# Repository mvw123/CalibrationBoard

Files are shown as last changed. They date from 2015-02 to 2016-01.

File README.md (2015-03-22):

CalibrationBoard
================

Reference board for calibration of Voltage, current, resistance Capacitance and Inductance
The design is created in Eagle CAD v 6.5.0 (free version) and uses the standard PCB board size.

CAD B - [WIP]
====================================
Work in progress

CAD A - [WIP]
====================================

The board has been manufactured at PCB fabricator ITead
Some issues have been noted with the PCB. See issues list in github. 

Basic tests indicate the board works, but needs a CAD B to correct some PCB issues. 

Specification: 
==============
Voltage reference -> 2.5V and 5.0V < 10mA load
Current Reference -> Configurable up to 10A max
Resistance references -> Various tight tolerance resistors <=1 ohm = 1%, >1 ohm = 0.1%
Capacitors -> TBD
Inductors -> TBD

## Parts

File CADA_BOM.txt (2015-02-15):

Order list for /Users/guvvy/Documents/github/eagle/CalibrationBoard/CalibrationBoard.sch
Exported from EAGLE with DesignLink

Quantity	Value	Package	Order code	Manufacturer	Manuf. Code	Availability	Price (from)	Description
1	+9V_BATTERY_HOLDER	BC9VPC	unknown					
7	2.2uF	C0805	unknown					
3	0.1uF	C0805	unknown					
2	1uF	C0805	unknown					
1	47pF	C0805	2332727	AVX	08052U470FAT2A	3770	0.088	AVX - 08052U470FAT2A - CAP, MLCC, C0G/NP0, 47PF, 200V, 0805
1	1.2nF	C0805	1650948	VISHAY VITRAMON	VJ0805A122FXBMT	5863	0.0403	VISHAY VITRAMON - VJ0805A122FXBMT - CAP, MLCC, C0G/NP0, 1.2NF, 100V, 0805
1	10nF	C0805	unknown					
1	100nF	C0805	1740673	AVX	08055C104JAT2A	203426	0.0155	AVX - 08055C104JAT2A - CAP, MLCC, X7R, 100NF, 50V, 0805
1	10uF	C0805	unknown					
1	100uF	E5-10,5	unknown					
1	MBR60H100CTG	TO220ABS	1431072	ON SEMICONDUCTOR	MBR60H100CTG	665	0.501	ON SEMICONDUCTOR - MBR60H100CTG - DIODE, SCHOTTKY, 60A, 100V, TO-220
1	12A	LITTLEFUSE	1345957	TE CONNECTIVITY / RAYCHEM	RGEF1200	110	0.351	TE CONNECTIVITY / RAYCHEM - RGEF1200 - POLYSWITCH, RADIAL, 12A
1	1.1A	1812	1345925	TE CONNECTIVITY / RAYCHEM	MINISMDC110F/24-2	2983	0.188	TE CONNECTIVITY / RAYCHEM - MINISMDC110F/24-2 - POLYSWITCH, SMD, 1812, 1.1A
5	BANANA_CONN_RED	BANANA_CONN	1011402	HIRSCHMANN TEST AND MEASUREMENT	972354101	1602	2.04	HIRSCHMANN TEST AND MEASUREMENT - 972354101 - BANANA SOCKET, 32A, 4MM, PANEL, RED
4	BANANA_CONN_BLACK	BANANA_CONN	1011402	HIRSCHMANN TEST AND MEASUREMENT	972354101	1602	2.04	HIRSCHMANN TEST AND MEASUREMENT - 972354101 - BANANA SOCKET, 32A, 4MM, PANEL, RED
1	SK104-PAD	SK104-PAD	1319811	FISCHER ELEKTRONIK	SK 129 38,1 STS	231	1.14	FISCHER ELEKTRONIK - SK 129 38,1 STS - HEAT SINK, EXTRUDED, PCB MOUNTING
1	1nH	L1812	unknown					
1	330nH	L2825P	2333647	BOURNS	CW252016-R33G	1849	0.136	BOURNS - CW252016-R33G - INDUCTOR, 330NH, 2%, 0.5A, SMD
1	1uH	L1812	2287053	COILCRAFT	1812PS-102JLC	778	0.724	COILCRAFT - 1812PS-102JLC - INDUCTOR, PWR, 1UH, 2.7A, 5%, 685MHZ
1	100uH	L1812	2287073	COILCRAFT	1812PS-104JLB	75	0.63	COILCRAFT - 1812PS-104JLB - INDUCTOR, PWR, 100UH, 0.65A,5%,14MHZ
1	4.7mH	6000-XXXX-RC	2211696	WURTH ELEKTRONIK	7447721047	150	0.514	WURTH ELEKTRONIK - 7447721047 - INDUCTOR, POWER, 4700UH, 5%, 9.5X9.5MM
1	RED_LED	P-LCC-2	1519491	DIALIGHT	597-3121-207F	1506	0.148	DIALIGHT - 597-3121-207F - LED, PLCC, RED
1	OSHW-LOGOL	OSHW-LOGO-L	unknown					
6	MOUNT_HOLE	3,81/1,4	unknown					
1	IRF3708PBF	TO220BV	8648158	INTERNATIONAL RECTIFIER	IRF3708PBF	30657	0.406	INTERNATIONAL RECTIFIER - IRF3708PBF - MOSFET, N, 30V, 62A, TO-220
1	2k	R0805	unknown					
1	25R	R0805	unknown					
1	0.1R	R0805	1717785	PANASONIC ELECTRONIC COMPONENTS	ERJ6RSFR10V	2973	0.051	PANASONIC ELECTRONIC COMPONENTS - ERJ6RSFR10V - RESISTOR, 0805, 0.125W, 1%, 0R1
1	1R	R0805	2333617	BOURNS	CR0805-FX-1R00ELF	10228	0.0107	BOURNS - CR0805-FX-1R00ELF - RESISTOR THICK FILM, 1OHM, 1%, 0805
1	5R	R0805	unknown					
1	10R	R0805	2008313	BOURNS	CRT0805-BY-10R0ELF	8362	0.0876	BOURNS - CRT0805-BY-10R0ELF - RESISTOR, 0805, 10R, 0.1%, 1/8W
1	50R	R0805	unknown					
1	100R	R0805	1653279	SUSUMU	RR1220P-101-B-T5	2178	0.0536	SUSUMU - RR1220P-101-B-T5 - THIN FILM CHIP RESISTOR
1	1k	R0805	1577659	PANASONIC ELECTRONIC COMPONENTS	ERA6AEB102V	19999	0.0515	PANASONIC ELECTRONIC COMPONENTS - ERA6AEB102V - RESISTOR, THIN FILM, 1K, 0.125W, 0.1%
1	5k	R0805	unknown					
1	10k	R0805	1653282	SUSUMU	RR1220P-103-B-T5	25199	0.0536	SUSUMU - RR1220P-103-B-T5 - RESISTOR, THIN FILM, 10K, 0.1W, 0.1%
1	100k	R0805	1653285	SUSUMU	RR1220P-104-B-T5	13652	0.0524	SUSUMU - RR1220P-104-B-T5 - THIN FILM CHIP RESISTOR
1	1Meg	R0805	1653287	SUSUMU	RR1220P-105-B-T5	4133	0.0536	SUSUMU - RR1220P-105-B-T5 - THIN FILM CHIP RESISTOR
1	10Meg	R0805	unknown					
1	5649A	320-938	1082316	APEM	5649A	52	1.39	APEM - 5649A - SWITCH, DPDT, CTR OFF
49	TP_1MM_TH"	TP_1MM_TH	unknown					
2	MAX6126AASA25+	SOIC127P600X175-8N	1673170	MAXIM INTEGRATED PRODUCTS	MAX6126AASA25+	83	5.13	MAXIM INTEGRATED PRODUCTS - MAX6126AASA25+ - IC, V REF, ULTRA-HI, 2.5V, 8-SOIC
1	MAX6126AASA50+	SOIC127P600X175-8N	unknown

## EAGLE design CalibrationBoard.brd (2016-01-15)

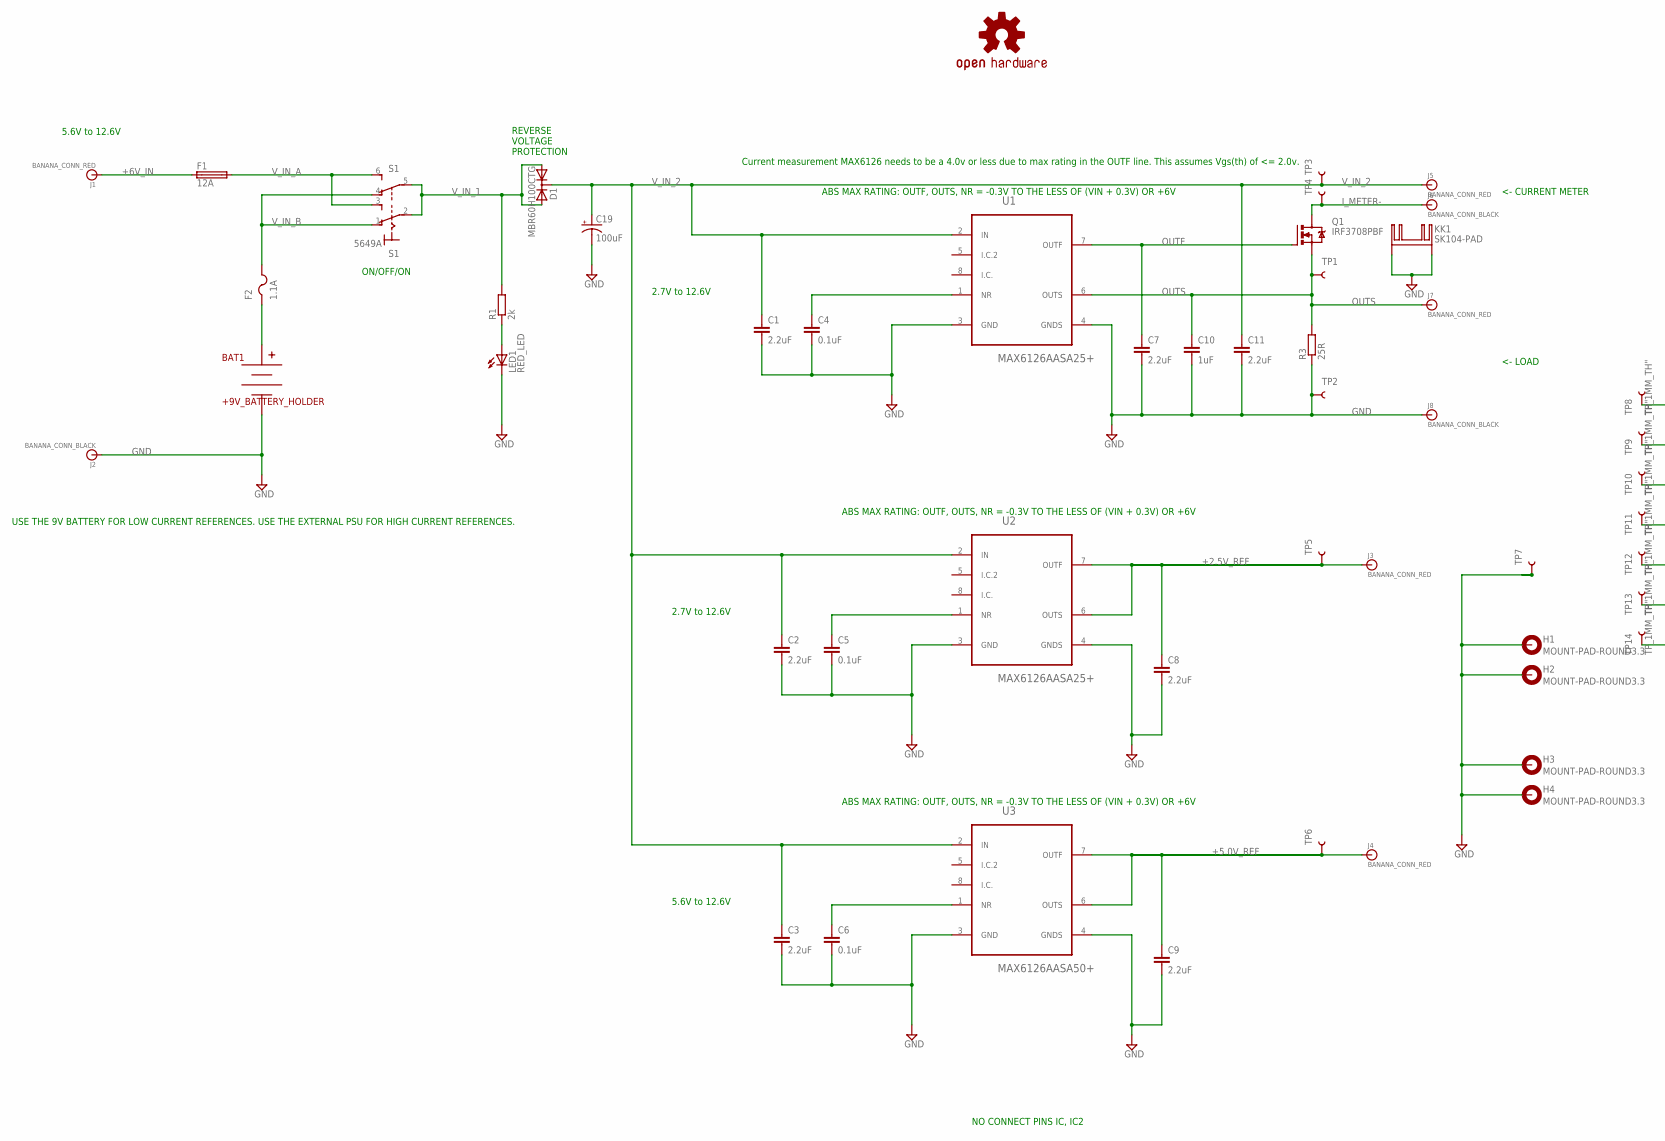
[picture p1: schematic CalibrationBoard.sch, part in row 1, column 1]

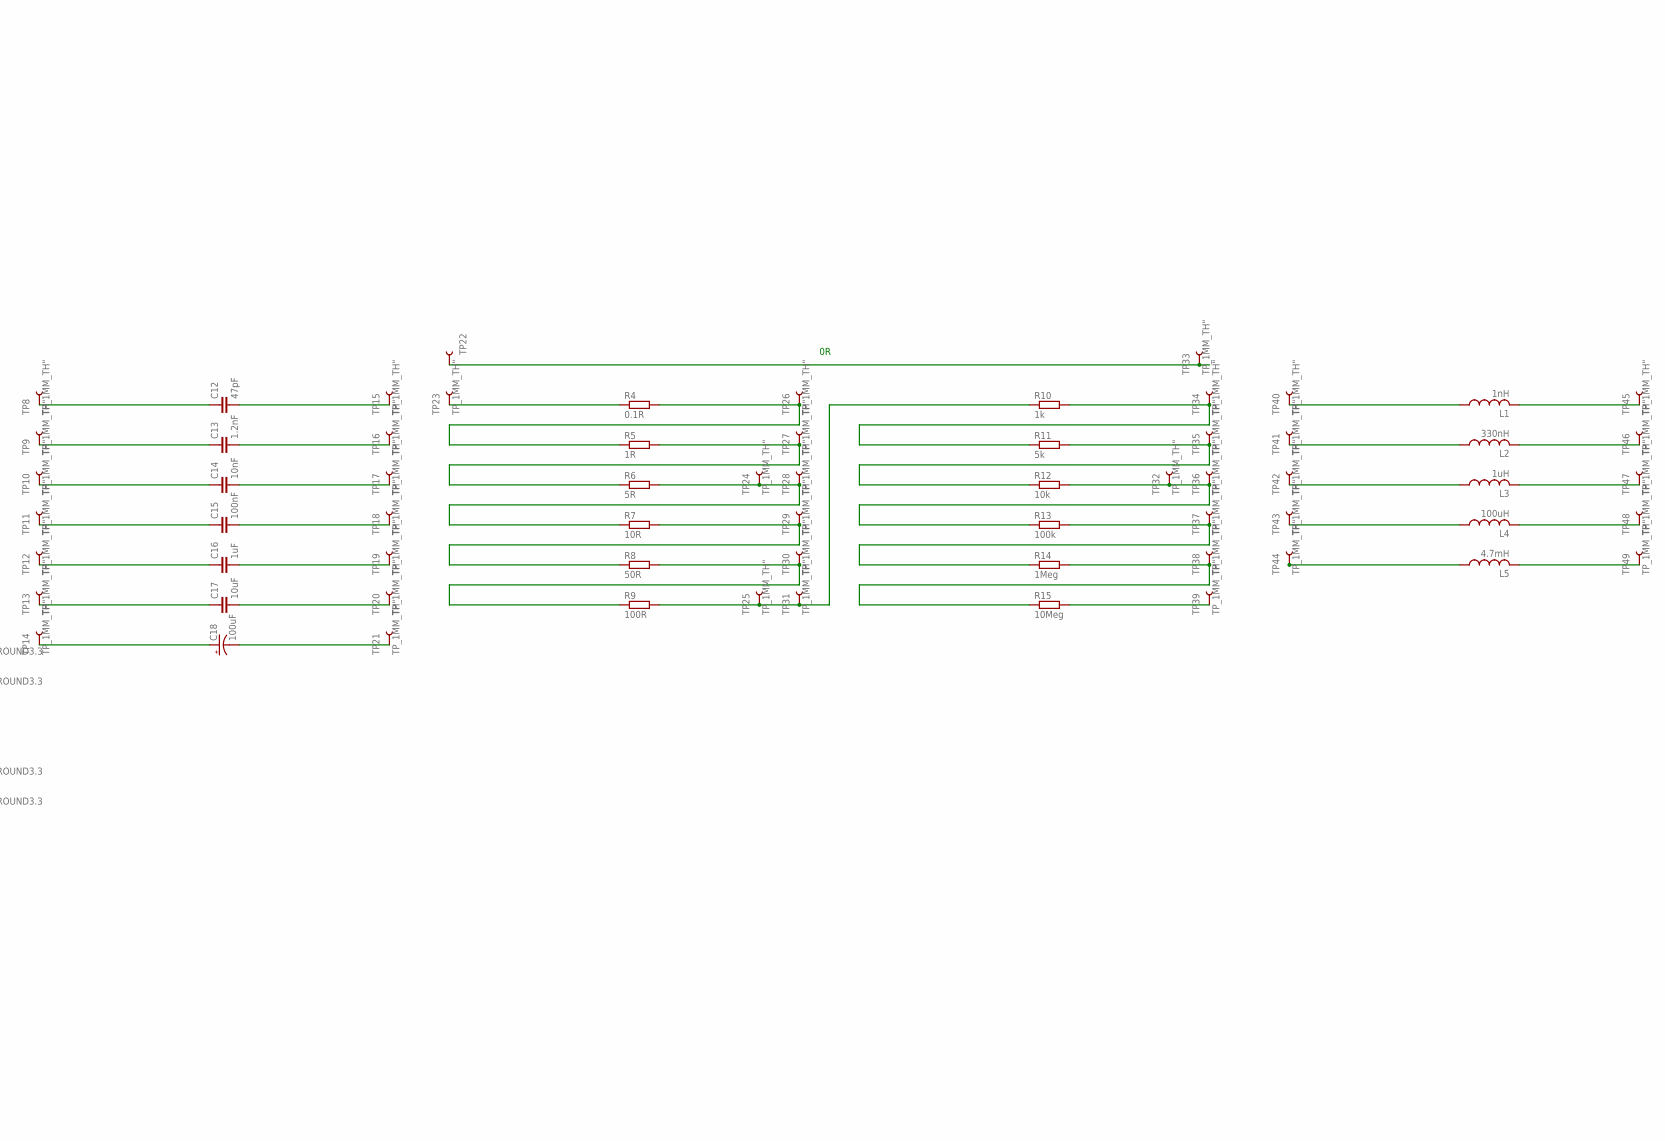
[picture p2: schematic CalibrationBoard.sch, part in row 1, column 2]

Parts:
BAT1: +9V_BATTERY_HOLDER; BC9VPC
C1, C2, C3, C7, C8, C9, C11: 2.2uF; C0805
C4, C5, C6: 0.1uF; C0805
C10, C16: 1uF; C0805
C12: 47pF; C0805; MPN 08052U470FAT2A
C13: 1.2nF; C0805; MPN VJ0805A122FXBMT
C14: 10nF; C0805
C15: 100nF; C0805; MPN 08055C104JAT2A
C17: 10uF; C0805
C18, C19: 100uF; E5-10,5
D1: MBR60H100CTG; TO220ABS; MPN MBR60H100CTG
F1: 12A; RGEF1200
F2: 1.1A; 1812; MPN MINISMDC110F/24-2
H1, H2, H3, H4: MOUNT-PAD-ROUND3.3; 3,3-PAD
J1, J3, J4, J5, J7: BANANA_CONN_RED; BANANA_CONN; MPN 972354101
J2, J6, J8: BANANA_CONN_BLACK; BANANA_CONN; MPN 972354101
KK1: SK104-PAD; MPN SK 129 38,1 STS
L1: 1nH; L1812
L2: 330nH; L2825P; MPN CW252016-R33G
L3: 1uH; L1812; MPN 1812PS-102JLC
L4: 100uH; L1812; MPN 1812PS-104JLB
L5: 4.7mH; 6000-XXXX-RC; MPN 7447721047
LED1: RED_LED; P-LCC-2; MPN 597-3121-207F
LOGO1: OSHW-LOGOL; OSHW-LOGO-L
Q1: IRF3708PBF; TO220BV; MPN IRF3708PBF
R1: 2k; R0805
R3: 25R; R0805
R4: 0.1R; R0805; MPN ERJ6RSFR10V
R5: 1R; R0805; MPN CR0805-FX-1R00ELF
R6: 5R; R0805
R7: 10R; R0805; MPN CRT0805-BY-10R0ELF
R8: 50R; R0805
R9: 100R; R0805; MPN RR1220P-101-B-T5
R10: 1k; R0805; MPN ERA6AEB102V
R11: 5k; R0805
R12: 10k; R0805; MPN RR1220P-103-B-T5
R13: 100k; R0805; MPN RR1220P-104-B-T5
R14: 1Meg; R0805; MPN RR1220P-105-B-T5
R15: 10Meg; R0805
S1: 5649A; 320-938; MPN 5649A
TP1, TP2, TP3, TP4, TP5, TP6, TP7, TP8, TP9, TP10, TP11, TP12, TP13, TP14, TP15, TP16, TP17, TP18, TP19, TP20, TP21, TP22, TP23, TP24, TP25, TP26, TP27, TP28, TP29, TP30, TP31, TP32, TP33, TP34, TP35, TP36, TP37, TP38, TP39, TP40, TP41, TP42, TP43, TP44, TP45, TP46, TP47, TP48, TP49: TP_1MM_TH"; TP_1MM_TH; MPN TEST-3
U1, U2: MAX6126AASA25+; SOIC127P600X175-8N; MPN MAX6126AASA25+
U3: MAX6126AASA50+; SOIC127P600X175-8N

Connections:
+2.5V_REF: C8.1, J3.P$1, TP5.P$1, U2.6 (OUTS), U2.7 (OUTF)
+5.0V_REF: C9.1, J4.P$1, TP6.P$1, U3.6 (OUTS), U3.7 (OUTF)
+6V_IN: F1.1, J1.P$1
GND: BAT1.V-, C1.2, C2.2, C3.2, C4.2, C5.2, C6.2, C7.2, C8.2, C9.2, C10.2, C11.2, C19.-, H1.B3,3, H2.B3,3, H3.B3,3, H4.B3,3, J2.P$1, J8.P$1, KK1.K1, KK1.K2, LED1.C, R3.1, TP2.P$1, TP7.P$1, U1.3 (GND), U1.4 (GNDS), U2.3 (GND), U2.4 (GNDS), U3.3 (GND), U3.4 (GNDS)
I_METER-: J6.P$1, Q1.D, TP4.P$1
unnamed: C12.1, TP8.P$1
unnamed: L1.2, TP45.P$1
unnamed: R4.1, TP23.P$1
unnamed: C6.1, U3.1 (NR)
unnamed: L2.2, TP46.P$1
unnamed: R8.2, R9.1, TP30.P$1
unnamed: BAT1.V+, F2.1
unnamed: R4.2, R5.1, TP26.P$1
unnamed: C17.2, TP20.P$1
unnamed: R9.2, R10.1, TP25.P$1, TP31.P$1
unnamed: R10.2, R11.1, TP34.P$1
unnamed: L3.2, TP47.P$1
unnamed: C5.1, U2.1 (NR)
unnamed: R11.2, R12.1, TP35.P$1
unnamed: R13.2, R14.1, TP37.P$1
unnamed: R6.2, R7.1, TP24.P$1, TP28.P$1
unnamed: L4.2, TP48.P$1
unnamed: L5.2, TP49.P$1
unnamed: R14.2, R15.1, TP38.P$1
unnamed: TP22.P$1, TP33.P$1
unnamed: L1.1, TP40.P$1
unnamed: R15.2, TP39.P$1
unnamed: C18.+, TP14.P$1
unnamed: C18.-, TP21.P$1
unnamed: C4.1, U1.1 (NR)
unnamed: R7.2, R8.1, TP29.P$1
unnamed: LED1.A, R1.1
unnamed: R5.2, R6.1, TP27.P$1
unnamed: R12.2, R13.1, TP32.P$1, TP36.P$1
unnamed: C12.2, TP15.P$1
unnamed: C13.2, TP16.P$1
unnamed: C14.2, TP17.P$1
unnamed: C15.2, TP18.P$1
unnamed: C16.2, TP19.P$1
unnamed: C13.1, TP9.P$1
unnamed: C14.1, TP10.P$1
unnamed: C15.1, TP11.P$1
unnamed: C16.1, TP12.P$1
unnamed: C17.1, TP13.P$1
unnamed: L5.1, TP44.P$1
unnamed: L4.1, TP43.P$1
unnamed: L3.1, TP42.P$1
unnamed: L2.1, TP41.P$1
OUTF: C7.1, Q1.G, U1.7 (OUTF)
OUTS: C10.1, J7.P$1, Q1.S, R3.2, TP1.P$1, U1.6 (OUTS)
V_IN_1: D1.A1, D1.A2, R1.2, S1.2, S1.5
V_IN_2: C1.1, C2.1, C3.1, C11.1, C19.+, D1.C, J5.P$1, TP3.P$1, U1.2 (IN), U2.2 (IN), U3.2 (IN)
V_IN_A: F1.2, S1.3 (S), S1.6 (S)
V_IN_B: F2.2, S1.1 (O), S1.4 (O)

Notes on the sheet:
Current measurement MAX6126 needs to be a 4.0v or less due to max rating in the OUTF line. This assumes Vgs(th) of <= 2.0v.
2.7V to 12.6V
ABS MAX RATING: OUTF, OUTS, NR = -0.3V TO THE LESS OF (VIN + 0.3V) OR +6V
5.6V to 12.6V
<- LOAD
<- CURRENT METER
USE THE 9V BATTERY FOR LOW CURRENT REFERENCES. USE THE EXTERNAL PSU FOR HIGH CURRENT REFERENCES.
NO CONNECT PINS IC, IC2
REVERSE VOLTAGE PROTECTION
ON/OFF/ON

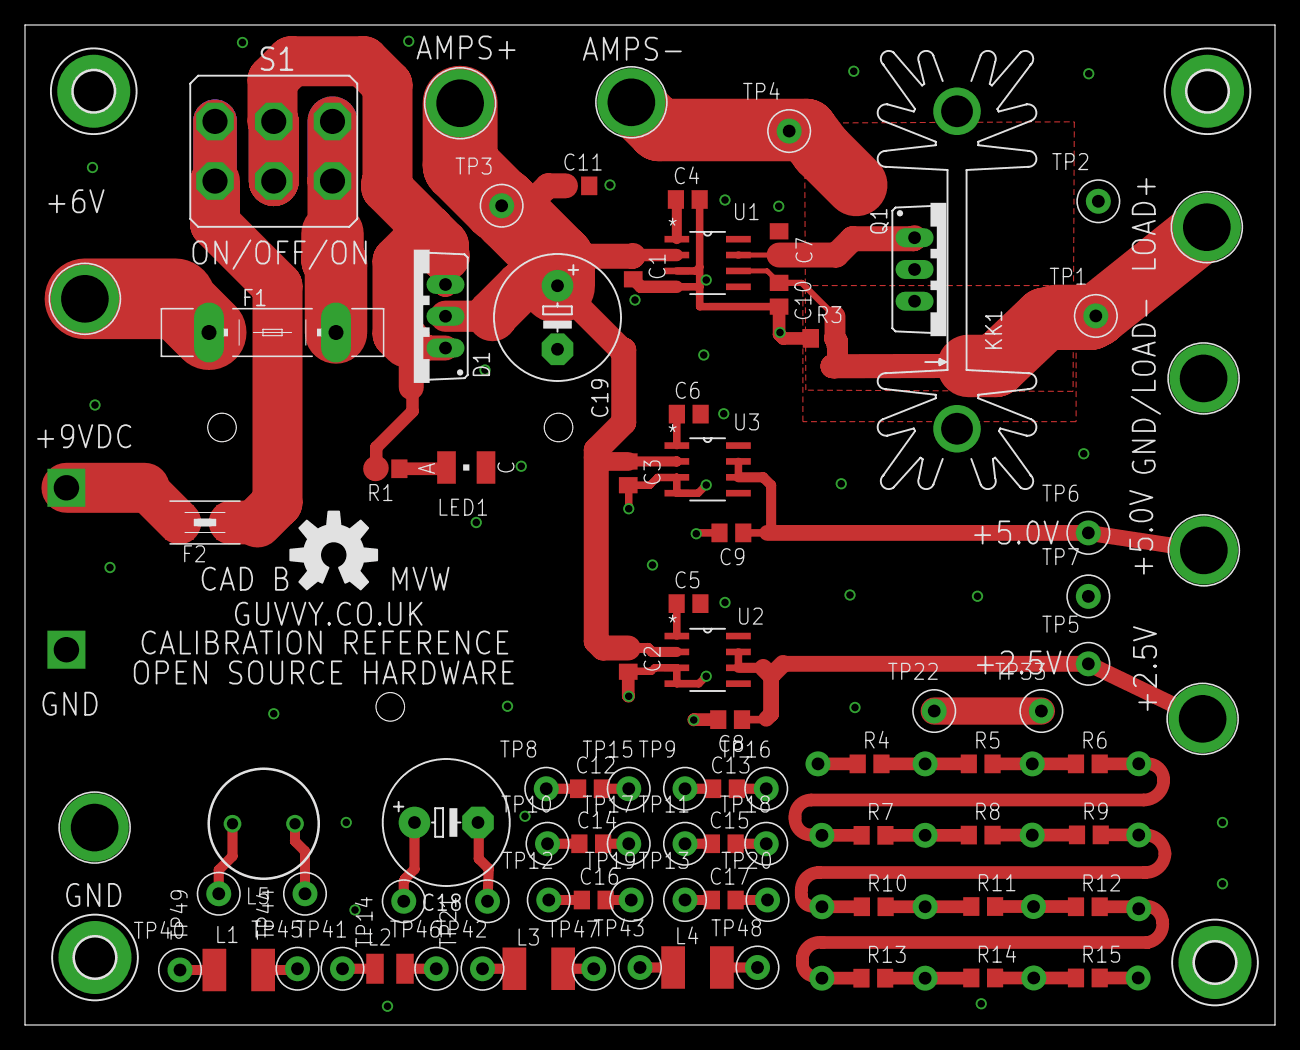
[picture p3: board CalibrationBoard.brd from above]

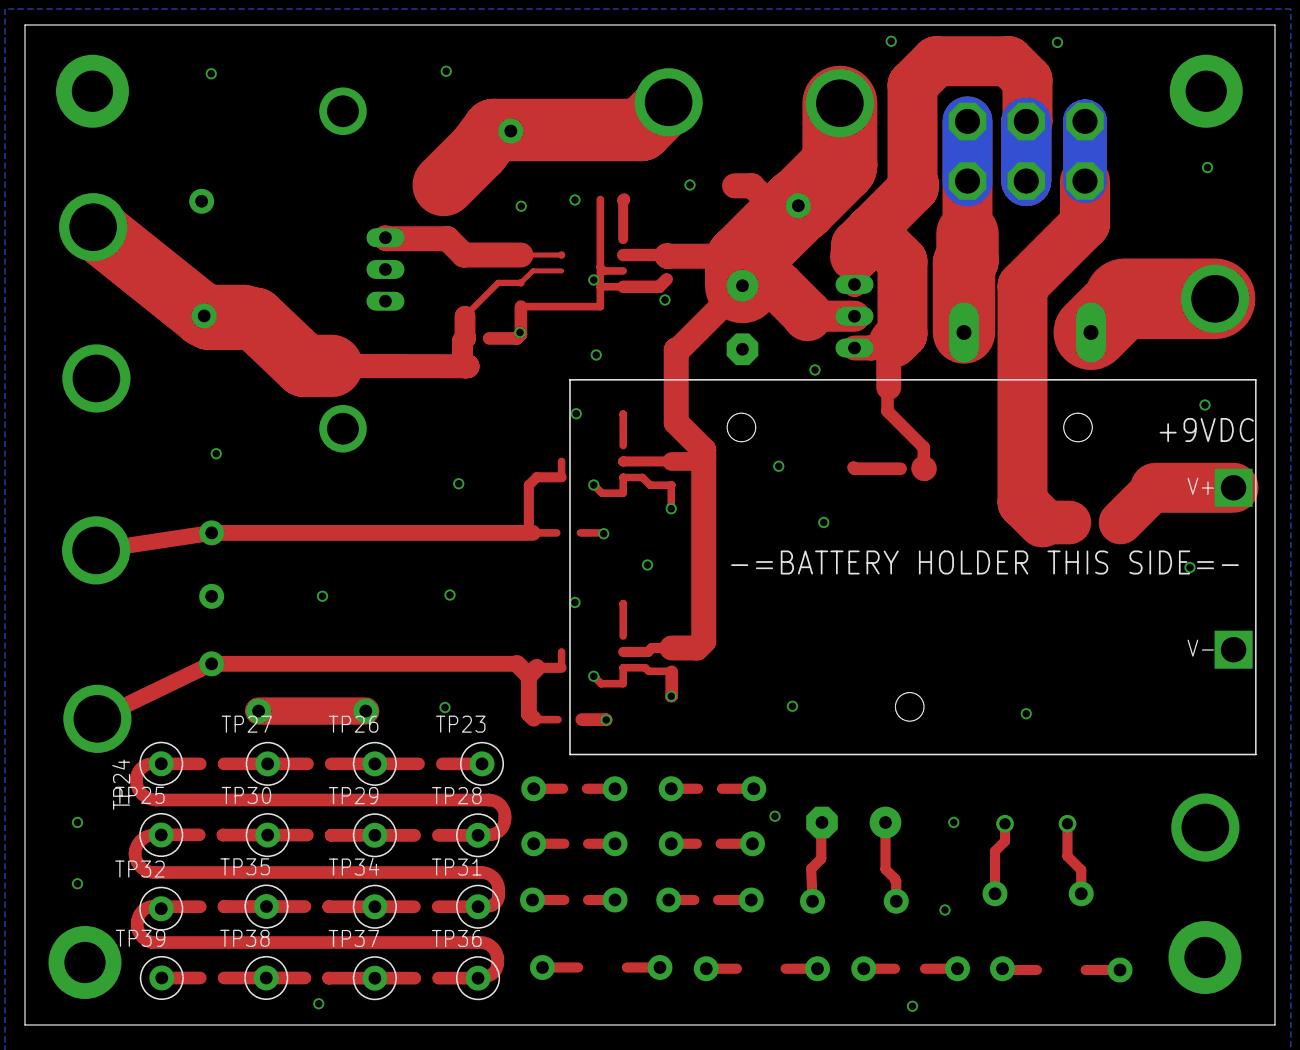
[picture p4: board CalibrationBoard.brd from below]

Board: 2 copper layers, 100.0 x 80.0 mm, 111 parts (17 on the bottom side), 54 nets.

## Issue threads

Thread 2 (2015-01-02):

Bannanananana socket hole may not be correct size, also various hole sizes are used

mvw123, 2015-01-02:
Bannanananana socket hole may not be correct size, also various hole sizes are used
hole appears to be 3.8mm
M3, M4 M6 are used .
need to check the cost / size advantages

mvw123, 2015-01-02:
consider
Brand
Hirschmann Test & Measurement
Mfr. Part No.
930147700

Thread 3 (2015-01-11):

CAD A issues and required improvements

mvw123, 2015-01-11:
* Banana socket are the wrong size and too close together.
* Forgot to buy switches and test connectors
* It is not clear if the switch is the correct type, it may not actually be a through hole switch!
* PAD1-6 holes are too small
* Heatsink is better as the shorter, wider heatsink sample purchased, the tall one doesn't look right. But the shorter fatter one covers a test point so this needs adjusting.
* The above heatsink will probably also clash with the banana sockets
* F1 through holes were much too small for this fuse. needs a proper part creating for it.
* The battery holder is a type which can have the battery inserted either way around. Convert over to a type which only allows the battery to be inserted one way around.
* Currently the board is about 10cmx8cm, check the exact side is correct for production at ITead
* Text around the open source symbol would benefit from slight location adjustment

MW

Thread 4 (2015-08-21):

Need to finish calibrating the 1 ohm load resistor.

mvw123, 2015-08-21:
Need to finish calibrating the 1 ohm load resistor.
The high power 1 ohm load resistor is slightly above 1 ohm and can be calibrated by adding a parallel resistor to bring it in specification.
10 x 10 ohm 0.1% cal resistors were used to calculated v drop and thus resistance.
Kelvin sense wires would then be needed to remove the connector resistances from the result.

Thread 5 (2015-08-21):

Cost down ideas

mvw123, 2015-08-21:
Ideas for cost downs

Use one calibrated 10V reference with an adjustable trimmer pot to set the output accurately.
Dial the 10v down through resistors to produce the other voltage required
Remove the banana/binding post sockets and put all connection points on board
Acrylic top/bottom cover, to allow storage on a bookshelf

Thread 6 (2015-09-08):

FET not suitable

mvw123, 2015-09-08:
FET not suitable
i been suckered!
datasheet indicates 2.0V max V(GSth), but this is at 250uA.
elsewhere it indicates 2.8v @ 7.5A @ 25C
The MAX6126 maximum ratings indicate OUTF, OUTS, NR........ -0.3V to the lesser of (VIN + 0.3V) or +6V.
So 6v - 2.5V gives a maximum V(gsth) of 3.5V. which this device will meet if we ensure the current through it remains low. but could exceed the upper limit with higher current or even a short circuit. hrm.

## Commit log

2014-11-24 First Commit of CAD A - Still WIP
    First Commit of CAD A - Still WIP
    Needs ICs changing to MX6126 to allow only 9V operation and various
    other updates.
    [CalibrationBoard.brd, CalibrationBoard.sch]
2014-12-10 Updates to CAD layout
    moved TH to top side, SMDs are on bottom side
    [CalibrationBoard.brd, CalibrationBoard.sch]
2014-12-21 Added capacitors and inductors
    Added capacitors and inductors and corrected some ERC errors
    [CalibrationBoard.brd, CalibrationBoard.sch]
2014-12-27 Updates before PCB release to Fabrication
    Updates before PCB release to Fabrication.
    Component part numbers for purchase still need specifying.
    [CalibrationBoard.brd, CalibrationBoard.sch]
2014-12-27 Updated read description to mention eagle cad
    Updated read description to mention eagle cad
2014-12-31 Various minor changes with minor CAD impacts
    Connected some minor air nets (no CAD issues)
    Changed NR caps from 1uF to 0.1uF as per DS.
    Moved a decoupling cap to allow ground flood to IC.
    Standardised the plane to track separation.
    [CalibrationBoard.brd, CalibrationBoard.sch]
2015-01-11 updates after initial testing of board.
    updates after initial testing of board.
2015-02-15 latest commits
    [CalibrationBoard.brd, CalibrationBoard.sch]
2016-01-15 latest updates
    [CalibrationBoard.brd, CalibrationBoard.sch]

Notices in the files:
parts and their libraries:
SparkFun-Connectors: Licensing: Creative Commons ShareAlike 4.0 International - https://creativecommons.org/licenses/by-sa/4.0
